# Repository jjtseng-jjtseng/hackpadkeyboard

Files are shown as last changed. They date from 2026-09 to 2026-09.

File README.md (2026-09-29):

# My HackPad Keyboard

A keyboard that can type an absurdly large amount of characters in a short space.
By combining the 16 keys with the knob, each turn of the knob makes each key type a different thing. This way, you can go from your normal A B C's to weird hieroglyphics.

# Features/Things used:

- 3d printed case (bottom section with a usb c hole wita top cover with a knob and key hole(s))
- 99.5 x99.5 mm pcb with a 4x4 matrix of buttons on it (+ knob)
- 16 LED's for each of buttons (cool lighting effects)

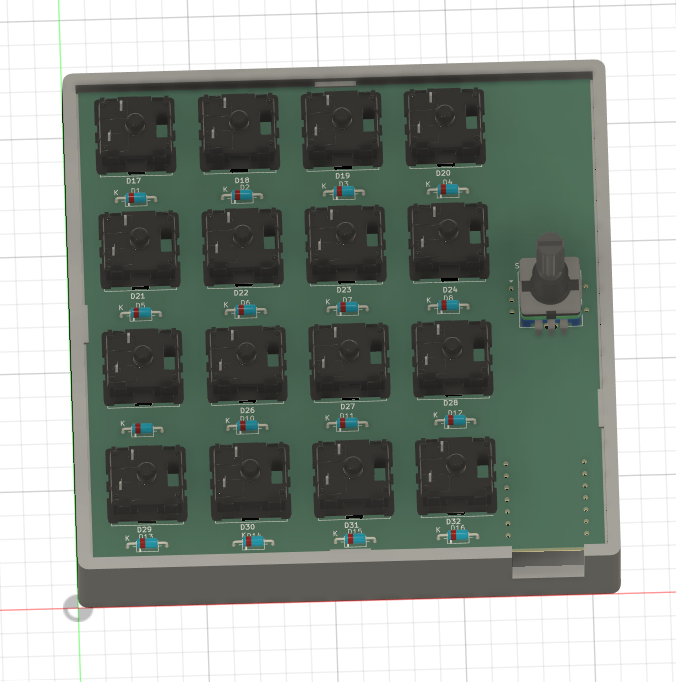
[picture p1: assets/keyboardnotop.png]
Top View

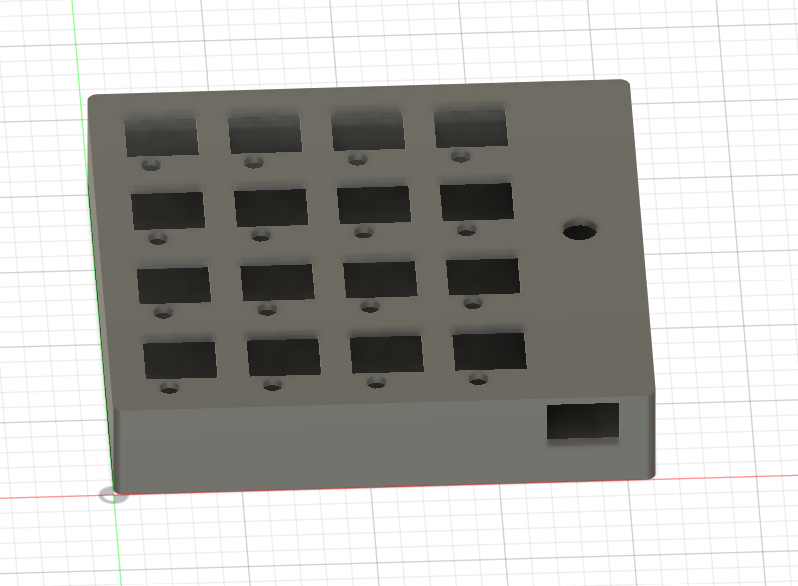
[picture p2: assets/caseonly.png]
Caseonly


# CAD
Used fusion 360
Pretty easy. Bottom case with usb c hole + top case with key, knob, and LED holes.

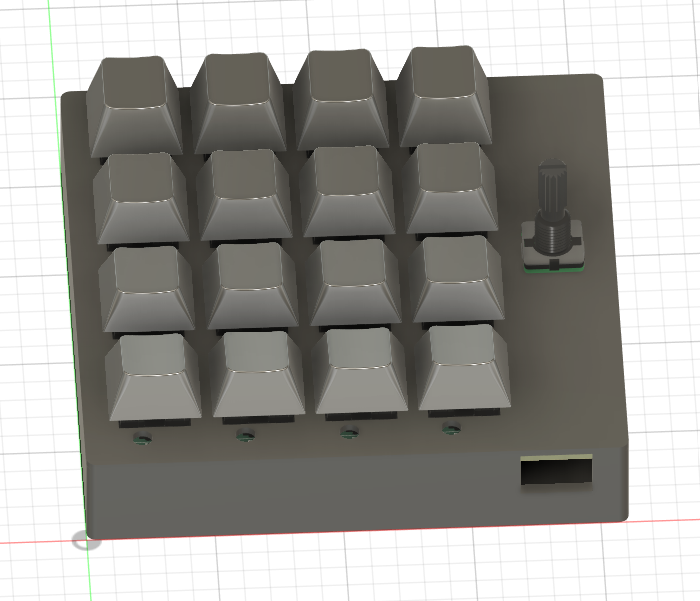
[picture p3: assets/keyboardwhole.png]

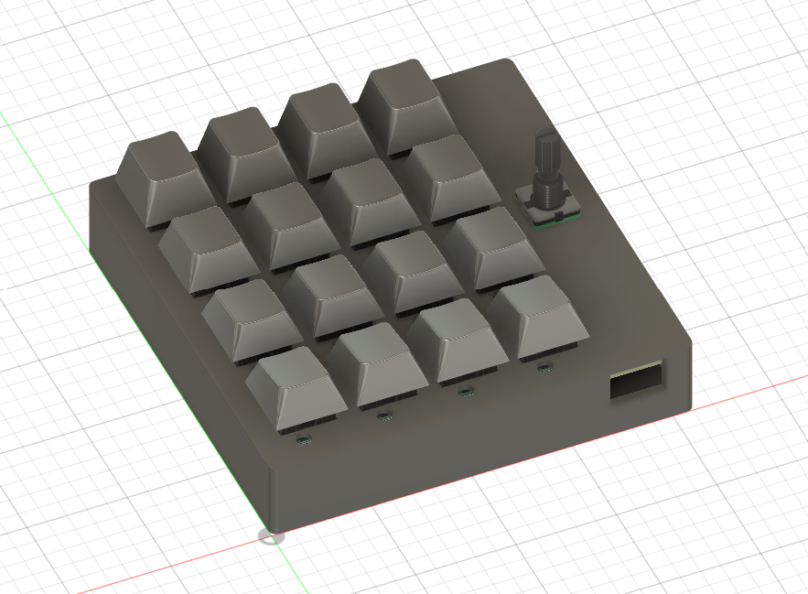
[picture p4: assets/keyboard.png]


# PCB

PCB pics attached below.
Kicad used

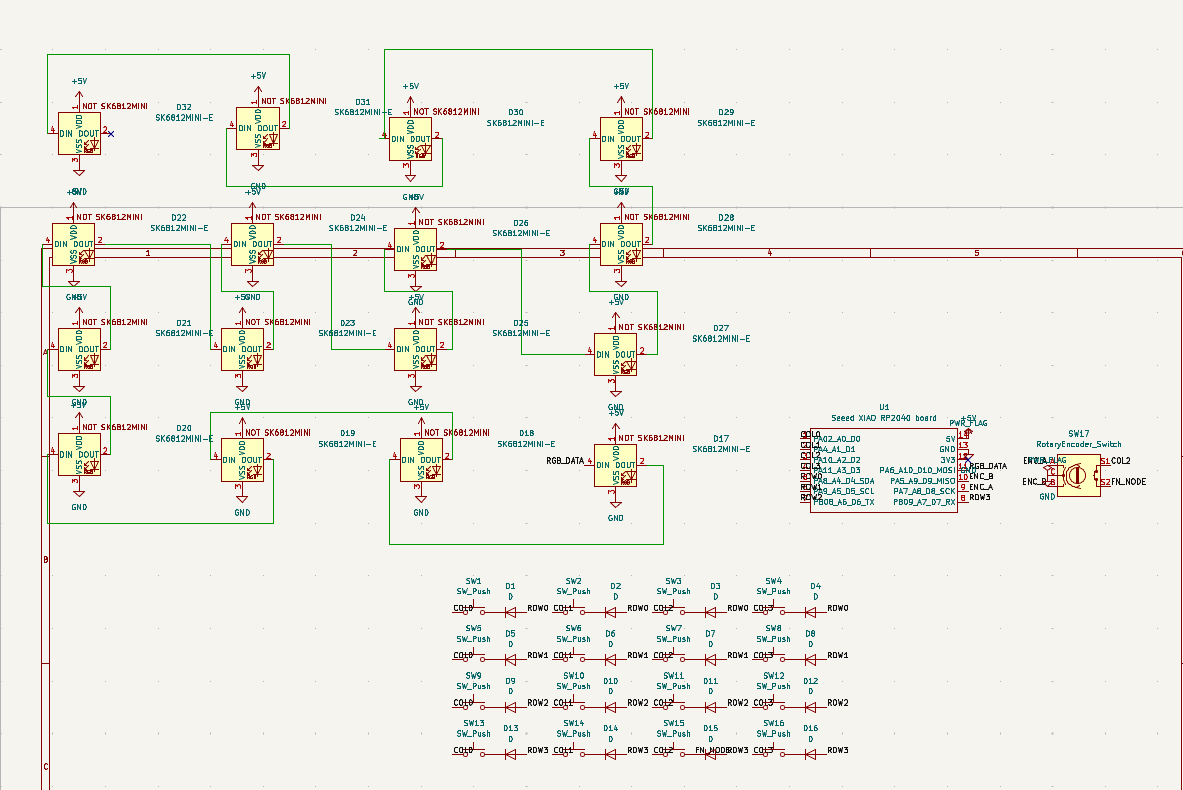
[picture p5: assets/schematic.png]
Schematic

Schematic
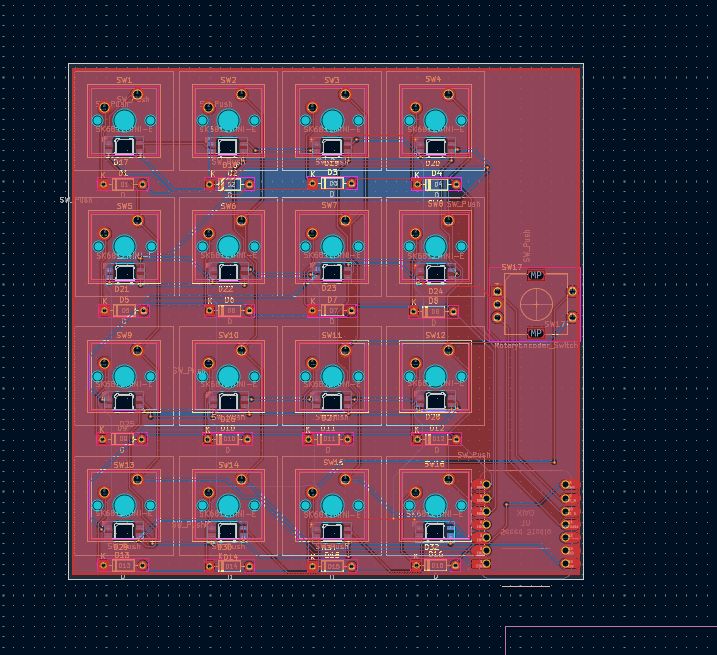
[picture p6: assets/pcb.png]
PCB

PCB
CAD render:
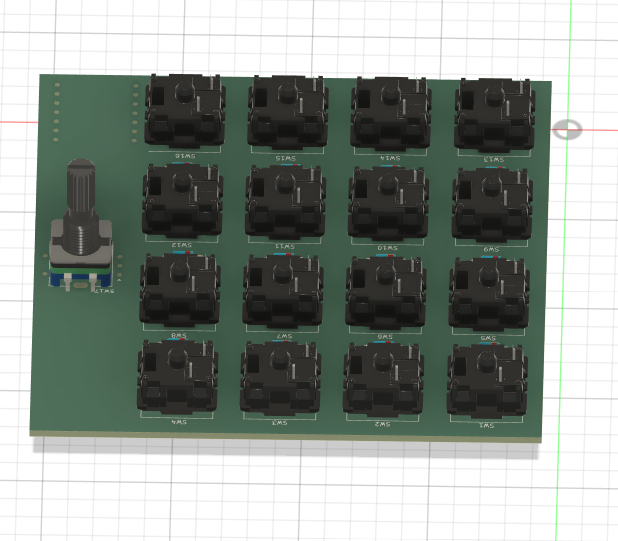
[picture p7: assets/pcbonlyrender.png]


# Firmware:
Python with a main.py used.

#How the final product should look:

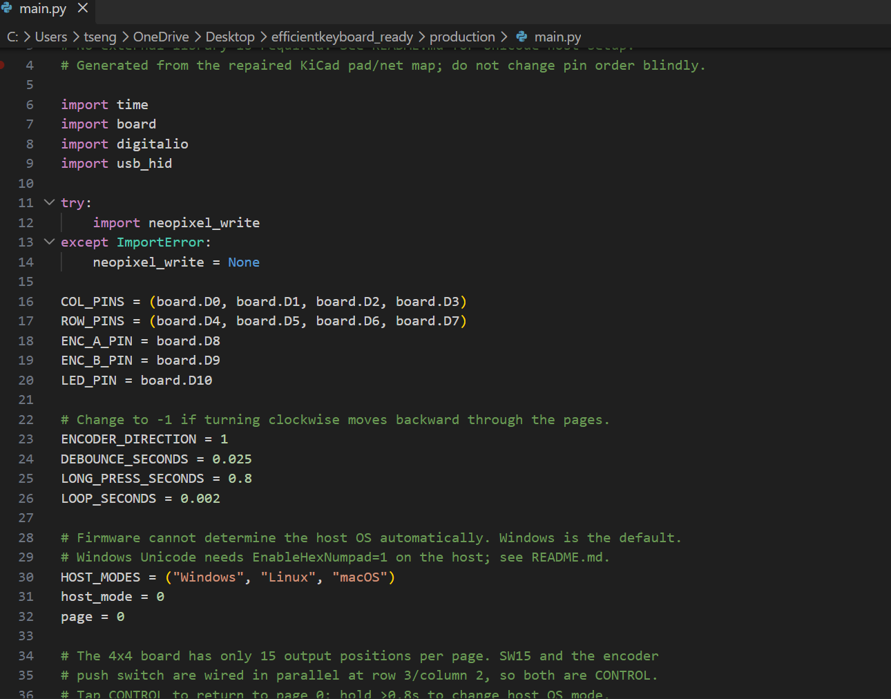
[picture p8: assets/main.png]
Code

Main.py

# BOM

Everything that is needed to make this:

- 1x custom pcb
- 1x Rotary encoder
- 1x Seeed XIAO RP2040
- 16x SK6812MINI-E RGB LEDs
- 16x DSA keycaps
- 16x 1N4148 Diodes
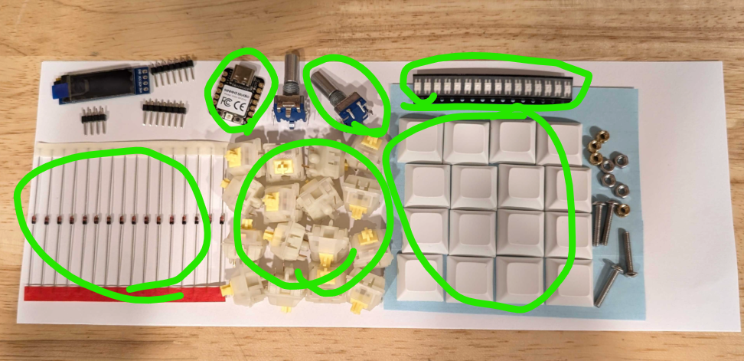
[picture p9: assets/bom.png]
stuffused


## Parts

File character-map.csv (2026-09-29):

Page | Name | SW1 | SW2 | SW3 | SW4 | SW5 | SW6 | SW7 | SW8 | SW9 | SW10 | SW11 | SW12 | SW13 | SW14 | SW15 | SW16
0 | QWERTY 1 | q | w | e | r | t | y | u | i | o | p | a | s | d | f | CONTROL | g
1 | QWERTY 2 | h | j | k | l | z | x | c | v | b | n | m | SPACE | BACKSPACE | ENTER | CONTROL | TAB
2 | Digits | 1 | 2 | 3 | 4 | 5 | 6 | 7 | 8 | 9 | 0 | - | = | , | . | CONTROL | /
3 | Common symbols | ! | @ | # | $ | % | ^ | & | * | ( | ) | _ | + | ? | : | CONTROL | ;
4 | More symbols | [ | ] | { | } | \ | | | ~ | < | > | " | ' | ` | A | ESCAPE | CONTROL | DELETE
5 | Latin 1 1 | ¡ U+00A1 | ¢ U+00A2 | £ U+00A3 | ¤ U+00A4 | ¥ U+00A5 | ¦ U+00A6 | § U+00A7 | ¨ U+00A8 | © U+00A9 | ª U+00AA | « U+00AB | ¬ U+00AC | ® U+00AE | ¯ U+00AF | CONTROL | ° U+00B0
6 | Latin 1 2 | ± U+00B1 | ² U+00B2 | ³ U+00B3 | ´ U+00B4 | µ U+00B5 | ¶ U+00B6 | · U+00B7 | ¸ U+00B8 | ¹ U+00B9 | º U+00BA | » U+00BB | ¼ U+00BC | ½ U+00BD | ¾ U+00BE | CONTROL | ¿ U+00BF
7 | Latin 1 3 | À U+00C0 | Á U+00C1 | Â U+00C2 | Ã U+00C3 | Ä U+00C4 | Å U+00C5 | Æ U+00C6 | Ç U+00C7 | È U+00C8 | É U+00C9 | Ê U+00CA | Ë U+00CB | Ì U+00CC | Í U+00CD | CONTROL | Î U+00CE
8 | Latin Extended A 1 | Ā U+0100 | ā U+0101 | Ă U+0102 | ă U+0103 | Ą U+0104 | ą U+0105 | Ć U+0106 | ć U+0107 | Ĉ U+0108 | ĉ U+0109 | Ċ U+010A | ċ U+010B | Č U+010C | č U+010D | CONTROL | Ď U+010E
9 | Latin Extended A 2 | ď U+010F | Đ U+0110 | đ U+0111 | Ē U+0112 | ē U+0113 | Ĕ U+0114 | ĕ U+0115 | Ė U+0116 | ė U+0117 | Ę U+0118 | ę U+0119 | Ě U+011A | ě U+011B | Ĝ U+011C | CONTROL | ĝ U+011D
10 | Latin Extended A 3 | Ğ U+011E | ğ U+011F | Ġ U+0120 | ġ U+0121 | Ģ U+0122 | ģ U+0123 | Ĥ U+0124 | ĥ U+0125 | Ħ U+0126 | ħ U+0127 | Ĩ U+0128 | ĩ U+0129 | Ī U+012A | ī U+012B | CONTROL | Ĭ U+012C
11 | Latin Extended A 4 | ĭ U+012D | Į U+012E | į U+012F | İ U+0130 | ı U+0131 | Ĳ U+0132 | ĳ U+0133 | Ĵ U+0134 | ĵ U+0135 | Ķ U+0136 | ķ U+0137 | ĸ U+0138 | Ĺ U+0139 | ĺ U+013A | CONTROL | Ļ U+013B
12 | Latin Extended A 5 | ļ U+013C | Ľ U+013D | ľ U+013E | Ŀ U+013F | ŀ U+0140 | Ł U+0141 | ł U+0142 | Ń U+0143 | ń U+0144 | Ņ U+0145 | ņ U+0146 | Ň U+0147 | ň U+0148 | ŉ U+0149 | CONTROL | Ŋ U+014A
13 | Latin Extended B 1 | ƀ U+0180 | Ɓ U+0181 | Ƃ U+0182 | ƃ U+0183 | Ƅ U+0184 | ƅ U+0185 | Ɔ U+0186 | Ƈ U+0187 | ƈ U+0188 | Ɖ U+0189 | Ɗ U+018A | Ƌ U+018B | ƌ U+018C | ƍ U+018D | CONTROL | Ǝ U+018E
14 | Latin Extended B 2 | Ə U+018F | Ɛ U+0190 | Ƒ U+0191 | ƒ U+0192 | Ɠ U+0193 | Ɣ U+0194 | ƕ U+0195 | Ɩ U+0196 | Ɨ U+0197 | Ƙ U+0198 | ƙ U+0199 | ƚ U+019A | ƛ U+019B | Ɯ U+019C | CONTROL | Ɲ U+019D
15 | Latin Extended B 3 | ƞ U+019E | Ɵ U+019F | Ơ U+01A0 | ơ U+01A1 | Ƣ U+01A2 | ƣ U+01A3 | Ƥ U+01A4 | ƥ U+01A5 | Ʀ U+01A6 | Ƨ U+01A7 | ƨ U+01A8 | Ʃ U+01A9 | ƪ U+01AA | ƫ U+01AB | CONTROL | Ƭ U+01AC
16 | Latin Extended B 4 | ƭ U+01AD | Ʈ U+01AE | Ư U+01AF | ư U+01B0 | Ʊ U+01B1 | Ʋ U+01B2 | Ƴ U+01B3 | ƴ U+01B4 | Ƶ U+01B5 | ƶ U+01B6 | Ʒ U+01B7 | Ƹ U+01B8 | ƹ U+01B9 | ƺ U+01BA | CONTROL | ƻ U+01BB
17 | IPA 1 | ɐ U+0250 | ɑ U+0251 | ɒ U+0252 | ɓ U+0253 | ɔ U+0254 | ɕ U+0255 | ɖ U+0256 | ɗ U+0257 | ɘ U+0258 | ə U+0259 | ɚ U+025A | ɛ U+025B | ɜ U+025C | ɝ U+025D | CONTROL | ɞ U+025E
18 | IPA 2 | ɟ U+025F | ɠ U+0260 | ɡ U+0261 | ɢ U+0262 | ɣ U+0263 | ɤ U+0264 | ɥ U+0265 | ɦ U+0266 | ɧ U+0267 | ɨ U+0268 | ɩ U+0269 | ɪ U+026A | ɫ U+026B | ɬ U+026C | CONTROL | ɭ U+026D
19 | Greek 1 | Ͱ U+0370 | ͱ U+0371 | Ͳ U+0372 | ͳ U+0373 | ʹ U+0374 | ͵ U+0375 | Ͷ U+0376 | ͷ U+0377 | ͺ U+037A | ͻ U+037B | ͼ U+037C | ͽ U+037D | ; U+037E | Ϳ U+037F | CONTROL | ΄ U+0384
20 | Greek 2 | ΅ U+0385 | Ά U+0386 | · U+0387 | Έ U+0388 | Ή U+0389 | Ί U+038A | Ό U+038C | Ύ U+038E | Ώ U+038F | ΐ U+0390 | Α U+0391 | Β U+0392 | Γ U+0393 | Δ U+0394 | CONTROL | Ε U+0395
21 | Greek 3 | Ζ U+0396 | Η U+0397 | Θ U+0398 | Ι U+0399 | Κ U+039A | Λ U+039B | Μ U+039C | Ν U+039D | Ξ U+039E | Ο U+039F | Π U+03A0 | Ρ U+03A1 | Σ U+03A3 | Τ U+03A4 | CONTROL | Υ U+03A5
22 | Greek 4 | Φ U+03A6 | Χ U+03A7 | Ψ U+03A8 | Ω U+03A9 | Ϊ U+03AA | Ϋ U+03AB | ά U+03AC | έ U+03AD | ή U+03AE | ί U+03AF | ΰ U+03B0 | α U+03B1 | β U+03B2 | γ U+03B3 | CONTROL | δ U+03B4
23 | Cyrillic 1 | Ѐ U+0400 | Ё U+0401 | Ђ U+0402 | Ѓ U+0403 | Є U+0404 | Ѕ U+0405 | І U+0406 | Ї U+0407 | Ј U+0408 | Љ U+0409 | Њ U+040A | Ћ U+040B | Ќ U+040C | Ѝ U+040D | CONTROL | Ў U+040E
24 | Cyrillic 2 | Џ U+040F | А U+0410 | Б U+0411 | В U+0412 | Г U+0413 | Д U+0414 | Е U+0415 | Ж U+0416 | З U+0417 | И U+0418 | Й U+0419 | К U+041A | Л U+041B | М U+041C | CONTROL | Н U+041D
25 | Cyrillic 3 | О U+041E | П U+041F | Р U+0420 | С U+0421 | Т U+0422 | У U+0423 | Ф U+0424 | Х U+0425 | Ц U+0426 | Ч U+0427 | Ш U+0428 | Щ U+0429 | Ъ U+042A | Ы U+042B | CONTROL | Ь U+042C
26 | Cyrillic 4 | Э U+042D | Ю U+042E | Я U+042F | а U+0430 | б U+0431 | в U+0432 | г U+0433 | д U+0434 | е U+0435 | ж U+0436 | з U+0437 | и U+0438 | й U+0439 | к U+043A | CONTROL | л U+043B
27 | Cyrillic 5 | м U+043C | н U+043D | о U+043E | п U+043F | р U+0440 | с U+0441 | т U+0442 | у U+0443 | ф U+0444 | х U+0445 | ц U+0446 | ч U+0447 | ш U+0448 | щ U+0449 | CONTROL | ъ U+044A
28 | Armenian 1 | Ա U+0531 | Բ U+0532 | Գ U+0533 | Դ U+0534 | Ե U+0535 | Զ U+0536 | Է U+0537 | Ը U+0538 | Թ U+0539 | Ժ U+053A | Ի U+053B | Լ U+053C | Խ U+053D | Ծ U+053E | CONTROL | Կ U+053F
29 | Armenian 2 | Հ U+0540 | Ձ U+0541 | Ղ U+0542 | Ճ U+0543 | Մ U+0544 | Յ U+0545 | Ն U+0546 | Շ U+0547 | Ո U+0548 | Չ U+0549 | Պ U+054A | Ջ U+054B | Ռ U+054C | Ս U+054D | CONTROL | Վ U+054E
30 | Hebrew 1 | ־ U+05BE | ׀ U+05C0 | ׃ U+05C3 | ׆ U+05C6 | א U+05D0 | ב U+05D1 | ג U+05D2 | ד U+05D3 | ה U+05D4 | ו U+05D5 | ז U+05D6 | ח U+05D7 | ט U+05D8 | י U+05D9 | CONTROL | ך U+05DA
31 | Hebrew 2 | כ U+05DB | ל U+05DC | ם U+05DD | מ U+05DE | ן U+05DF | נ U+05E0 | ס U+05E1 | ע U+05E2 | ף U+05E3 | פ U+05E4 | ץ U+05E5 | צ U+05E6 | ק U+05E7 | ר U+05E8 | CONTROL | ש U+05E9
32 | Arabic 1 | ؆ U+0606 | ؇ U+0607 | ؈ U+0608 | ؉ U+0609 | ؊ U+060A | ؋ U+060B | ، U+060C | ؍ U+060D | ؎ U+060E | ؏ U+060F | ؛ U+061B | ؝ U+061D | ؞ U+061E | ؟ U+061F | CONTROL | ؠ U+0620
33 | Arabic 2 | ء U+0621 | آ U+0622 | أ U+0623 | ؤ U+0624 | إ U+0625 | ئ U+0626 | ا U+0627 | ب U+0628 | ة U+0629 | ت U+062A | ث U+062B | ج U+062C | ح U+062D | خ U+062E | CONTROL | د U+062F
34 | Arabic 3 | ذ U+0630 | ر U+0631 | ز U+0632 | س U+0633 | ش U+0634 | ص U+0635 | ض U+0636 | ط U+0637 | ظ U+0638 | ع U+0639 | غ U+063A | ػ U+063B | ؼ U+063C | ؽ U+063D | CONTROL | ؾ U+063E
35 | Devanagari 1 | ऄ U+0904 | अ U+0905 | आ U+0906 | इ U+0907 | ई U+0908 | उ U+0909 | ऊ U+090A | ऋ U+090B | ऌ U+090C | ऍ U+090D | ऎ U+090E | ए U+090F | ऐ U+0910 | ऑ U+0911 | CONTROL | ऒ U+0912
36 | Devanagari 2 | ओ U+0913 | औ U+0914 | क U+0915 | ख U+0916 | ग U+0917 | घ U+0918 | ङ U+0919 | च U+091A | छ U+091B | ज U+091C | झ U+091D | ञ U+091E | ट U+091F | ठ U+0920 | CONTROL | ड U+0921
37 | Bengali 1 | ঀ U+0980 | অ U+0985 | আ U+0986 | ই U+0987 | ঈ U+0988 | উ U+0989 | ঊ U+098A | ঋ U+098B | ঌ U+098C | এ U+098F | ঐ U+0990 | ও U+0993 | ঔ U+0994 | ক U+0995 | CONTROL | খ U+0996
38 | Tamil 1 | ஃ U+0B83 | அ U+0B85 | ஆ U+0B86 | இ U+0B87 | ஈ U+0B88 | உ U+0B89 | ஊ U+0B8A | எ U+0B8E | ஏ U+0B8F | ஐ U+0B90 | ஒ U+0B92 | ஓ U+0B93 | ஔ U+0B94 | க U+0B95 | CONTROL | ங U+0B99
39 | Thai 1 | ก U+0E01 | ข U+0E02 | ฃ U+0E03 | ค U+0E04 | ฅ U+0E05 | ฆ U+0E06 | ง U+0E07 | จ U+0E08 | ฉ U+0E09 | ช U+0E0A | ซ U+0E0B | ฌ U+0E0C | ญ U+0E0D | ฎ U+0E0E | CONTROL | ฏ U+0E0F
40 | Thai 2 | ฐ U+0E10 | ฑ U+0E11 | ฒ U+0E12 | ณ U+0E13 | ด U+0E14 | ต U+0E15 | ถ U+0E16 | ท U+0E17 | ธ U+0E18 | น U+0E19 | บ U+0E1A | ป U+0E1B | ผ U+0E1C | ฝ U+0E1D | CONTROL | พ U+0E1E
41 | Georgian 1 | Ⴀ U+10A0 | Ⴁ U+10A1 | Ⴂ U+10A2 | Ⴃ U+10A3 | Ⴄ U+10A4 | Ⴅ U+10A5 | Ⴆ U+10A6 | Ⴇ U+10A7 | Ⴈ U+10A8 | Ⴉ U+10A9 | Ⴊ U+10AA | Ⴋ U+10AB | Ⴌ U+10AC | Ⴍ U+10AD | CONTROL | Ⴎ U+10AE
42 | Georgian 2 | Ⴏ U+10AF | Ⴐ U+10B0 | Ⴑ U+10B1 | Ⴒ U+10B2 | Ⴓ U+10B3 | Ⴔ U+10B4 | Ⴕ U+10B5 | Ⴖ U+10B6 | Ⴗ U+10B7 | Ⴘ U+10B8 | Ⴙ U+10B9 | Ⴚ U+10BA | Ⴛ U+10BB | Ⴜ U+10BC | CONTROL | Ⴝ U+10BD
43 | Ethiopic 1 | ሀ U+1200 | ሁ U+1201 | ሂ U+1202 | ሃ U+1203 | ሄ U+1204 | ህ U+1205 | ሆ U+1206 | ሇ U+1207 | ለ U+1208 | ሉ U+1209 | ሊ U+120A | ላ U+120B | ሌ U+120C | ል U+120D | CONTROL | ሎ U+120E
44 | Ethiopic 2 | ሏ U+120F | ሐ U+1210 | ሑ U+1211 | ሒ U+1212 | ሓ U+1213 | ሔ U+1214 | ሕ U+1215 | ሖ U+1216 | ሗ U+1217 | መ U+1218 | ሙ U+1219 | ሚ U+121A | ማ U+121B | ሜ U+121C | CONTROL | ም U+121D
45 | Ethiopic 3 | ሞ U+121E | ሟ U+121F | ሠ U+1220 | ሡ U+1221 | ሢ U+1222 | ሣ U+1223 | ሤ U+1224 | ሥ U+1225 | ሦ U+1226 | ሧ U+1227 | ረ U+1228 | ሩ U+1229 | ሪ U+122A | ራ U+122B | CONTROL | ሬ U+122C
46 | Ethiopic 4 | ር U+122D | ሮ U+122E | ሯ U+122F | ሰ U+1230 | ሱ U+1231 | ሲ U+1232 | ሳ U+1233 | ሴ U+1234 | ስ U+1235 | ሶ U+1236 | ሷ U+1237 | ሸ U+1238 | ሹ U+1239 | ሺ U+123A | CONTROL | ሻ U+123B
47 | Cherokee 1 | Ꭰ U+13A0 | Ꭱ U+13A1 | Ꭲ U+13A2 | Ꭳ U+13A3 | Ꭴ U+13A4 | Ꭵ U+13A5 | Ꭶ U+13A6 | Ꭷ U+13A7 | Ꭸ U+13A8 | Ꭹ U+13A9 | Ꭺ U+13AA | Ꭻ U+13AB | Ꭼ U+13AC | Ꭽ U+13AD | CONTROL | Ꭾ U+13AE
48 | Cherokee 2 | Ꭿ U+13AF | Ꮀ U+13B0 | Ꮁ U+13B1 | Ꮂ U+13B2 | Ꮃ U+13B3 | Ꮄ U+13B4 | Ꮅ U+13B5 | Ꮆ U+13B6 | Ꮇ U+13B7 | Ꮈ U+13B8 | Ꮉ U+13B9 | Ꮊ U+13BA | Ꮋ U+13BB | Ꮌ U+13BC | CONTROL | Ꮍ U+13BD
49 | Canadian syllabics 1 | ᐀ U+1400 | ᐁ U+1401 | ᐂ U+1402 | ᐃ U+1403 | ᐄ U+1404 | ᐅ U+1405 | ᐆ U+1406 | ᐇ U+1407 | ᐈ U+1408 | ᐉ U+1409 | ᐊ U+140A | ᐋ U+140B | ᐌ U+140C | ᐍ U+140D | CONTROL | ᐎ U+140E
50 | Canadian syllabics 2 | ᐏ U+140F | ᐐ U+1410 | ᐑ U+1411 | ᐒ U+1412 | ᐓ U+1413 | ᐔ U+1414 | ᐕ U+1415 | ᐖ U+1416 | ᐗ U+1417 | ᐘ U+1418 | ᐙ U+1419 | ᐚ U+141A | ᐛ U+141B | ᐜ U+141C | CONTROL | ᐝ U+141D
51 | Canadian syllabics 3 | ᐞ U+141E | ᐟ U+141F | ᐠ U+1420 | ᐡ U+1421 | ᐢ U+1422 | ᐣ U+1423 | ᐤ U+1424 | ᐥ U+1425 | ᐦ U+1426 | ᐧ U+1427 | ᐨ U+1428 | ᐩ U+1429 | ᐪ U+142A | ᐫ U+142B | CONTROL | ᐬ U+142C
52 | Runic 1 | ᚠ U+16A0 | ᚡ U+16A1 | ᚢ U+16A2 | ᚣ U+16A3 | ᚤ U+16A4 | ᚥ U+16A5 | ᚦ U+16A6 | ᚧ U+16A7 | ᚨ U+16A8 | ᚩ U+16A9 | ᚪ U+16AA | ᚫ U+16AB | ᚬ U+16AC | ᚭ U+16AD | CONTROL | ᚮ U+16AE
53 | Runic 2 | ᚯ U+16AF | ᚰ U+16B0 | ᚱ U+16B1 | ᚲ U+16B2 | ᚳ U+16B3 | ᚴ U+16B4 | ᚵ U+16B5 | ᚶ U+16B6 | ᚷ U+16B7 | ᚸ U+16B8 | ᚹ U+16B9 | ᚺ U+16BA | ᚻ U+16BB | ᚼ U+16BC | CONTROL | ᚽ U+16BD
54 | Hiragana 1 | ぁ U+3041 | あ U+3042 | ぃ U+3043 | い U+3044 | ぅ U+3045 | う U+3046 | ぇ U+3047 | え U+3048 | ぉ U+3049 | お U+304A | か U+304B | が U+304C | き U+304D | ぎ U+304E | CONTROL | く U+304F
55 | Hiragana 2 | ぐ U+3050 | け U+3051 | げ U+3052 | こ U+3053 | ご U+3054 | さ U+3055 | ざ U+3056 | し U+3057 | じ U+3058 | す U+3059 | ず U+305A | せ U+305B | ぜ U+305C | そ U+305D | CONTROL | ぞ U+305E
56 | Katakana 1 | ゠ U+30A0 | ァ U+30A1 | ア U+30A2 | ィ U+30A3 | イ U+30A4 | ゥ U+30A5 | ウ U+30A6 | ェ U+30A7 | エ U+30A8 | ォ U+30A9 | オ U+30AA | カ U+30AB | ガ U+30AC | キ U+30AD | CONTROL | ギ U+30AE
57 | Katakana 2 | ク U+30AF | グ U+30B0 | ケ U+30B1 | ゲ U+30B2 | コ U+30B3 | ゴ U+30B4 | サ U+30B5 | ザ U+30B6 | シ U+30B7 | ジ U+30B8 | ス U+30B9 | ズ U+30BA | セ U+30BB | ゼ U+30BC | CONTROL | ソ U+30BD
58 | CJK 1 | 一 U+4E00 | 丁 U+4E01 | 丂 U+4E02 | 七 U+4E03 | 丄 U+4E04 | 丅 U+4E05 | 丆 U+4E06 | 万 U+4E07 | 丈 U+4E08 | 三 U+4E09 | 上 U+4E0A | 下 U+4E0B | 丌 U+4E0C | 不 U+4E0D | CONTROL | 与 U+4E0E
59 | CJK 2 | 丏 U+4E0F | 丐 U+4E10 | 丑 U+4E11 | 丒 U+4E12 | 专 U+4E13 | 且 U+4E14 | 丕 U+4E15 | 世 U+4E16 | 丗 U+4E17 | 丘 U+4E18 | 丙 U+4E19 | 业 U+4E1A | 丛 U+4E1B | 东 U+4E1C | CONTROL | 丝 U+4E1D
60 | CJK 3 | 丞 U+4E1E | 丟 U+4E1F | 丠 U+4E20 | 両 U+4E21 | 丢 U+4E22 | 丣 U+4E23 | 两 U+4E24 | 严 U+4E25 | 並 U+4E26 | 丧 U+4E27 | 丨 U+4E28 | 丩 U+4E29 | 个 U+4E2A | 丫 U+4E2B | CONTROL | 丬 U+4E2C
61 | Arrows 1 | ← U+2190 | ↑ U+2191 | → U+2192 | ↓ U+2193 | ↔ U+2194 | ↕ U+2195 | ↖ U+2196 | ↗ U+2197 | ↘ U+2198 | ↙ U+2199 | ↚ U+219A | ↛ U+219B | ↜ U+219C | ↝ U+219D | CONTROL | ↞ U+219E
62 | Arrows 2 | ↟ U+219F | ↠ U+21A0 | ↡ U+21A1 | ↢ U+21A2 | ↣ U+21A3 | ↤ U+21A4 | ↥ U+21A5 | ↦ U+21A6 | ↧ U+21A7 | ↨ U+21A8 | ↩ U+21A9 | ↪ U+21AA | ↫ U+21AB | ↬ U+21AC | CONTROL | ↭ U+21AD
63 | Math 1 | ∀ U+2200 | ∁ U+2201 | ∂ U+2202 | ∃ U+2203 | ∄ U+2204 | ∅ U+2205 | ∆ U+2206 | ∇ U+2207 | ∈ U+2208 | ∉ U+2209 | ∊ U+220A | ∋ U+220B | ∌ U+220C | ∍ U+220D | CONTROL | ∎ U+220E
64 | Math 2 | ∏ U+220F | ∐ U+2210 | ∑ U+2211 | − U+2212 | ∓ U+2213 | ∔ U+2214 | ∕ U+2215 | ∖ U+2216 | ∗ U+2217 | ∘ U+2218 | ∙ U+2219 | √ U+221A | ∛ U+221B | ∜ U+221C | CONTROL | ∝ U+221D
65 | Math 3 | ∞ U+221E | ∟ U+221F | ∠ U+2220 | ∡ U+2221 | ∢ U+2222 | ∣ U+2223 | ∤ U+2224 | ∥ U+2225 | ∦ U+2226 | ∧ U+2227 | ∨ U+2228 | ∩ U+2229 | ∪ U+222A | ∫ U+222B | CONTROL | ∬ U+222C
66 | Technical 1 | ⌀ U+2300 | ⌁ U+2301 | ⌂ U+2302 | ⌃ U+2303 | ⌄ U+2304 | ⌅ U+2305 | ⌆ U+2306 | ⌇ U+2307 | ⌈ U+2308 | ⌉ U+2309 | ⌊ U+230A | ⌋ U+230B | ⌌ U+230C | ⌍ U+230D | CONTROL | ⌎ U+230E
67 | Technical 2 | ⌏ U+230F | ⌐ U+2310 | ⌑ U+2311 | ⌒ U+2312 | ⌓ U+2313 | ⌔ U+2314 | ⌕ U+2315 | ⌖ U+2316 | ⌗ U+2317 | ⌘ U+2318 | ⌙ U+2319 | ⌚ U+231A | ⌛ U+231B | ⌜ U+231C | CONTROL | ⌝ U+231D
68 | Box drawing 1 | ─ U+2500 | ━ U+2501 | │ U+2502 | ┃ U+2503 | ┄ U+2504 | ┅ U+2505 | ┆ U+2506 | ┇ U+2507 | ┈ U+2508 | ┉ U+2509 | ┊ U+250A | ┋ U+250B | ┌ U+250C | ┍ U+250D | CONTROL | ┎ U+250E
69 | Box drawing 2 | ┏ U+250F | ┐ U+2510 | ┑ U+2511 | ┒ U+2512 | ┓ U+2513 | └ U+2514 | ┕ U+2515 | ┖ U+2516 | ┗ U+2517 | ┘ U+2518 | ┙ U+2519 | ┚ U+251A | ┛ U+251B | ├ U+251C | CONTROL | ┝ U+251D
70 | Geometric 1 | ■ U+25A0 | □ U+25A1 | ▢ U+25A2 | ▣ U+25A3 | ▤ U+25A4 | ▥ U+25A5 | ▦ U+25A6 | ▧ U+25A7 | ▨ U+25A8 | ▩ U+25A9 | ▪ U+25AA | ▫ U+25AB | ▬ U+25AC | ▭ U+25AD | CONTROL | ▮ U+25AE
71 | Geometric 2 | ▯ U+25AF | ▰ U+25B0 | ▱ U+25B1 | ▲ U+25B2 | △ U+25B3 | ▴ U+25B4 | ▵ U+25B5 | ▶ U+25B6 | ▷ U+25B7 | ▸ U+25B8 | ▹ U+25B9 | ► U+25BA | ▻ U+25BB | ▼ U+25BC | CONTROL | ▽ U+25BD
72 | Misc signs 1 | ☀ U+2600 | ☁ U+2601 | ☂ U+2602 | ☃ U+2603 | ☄ U+2604 | ★ U+2605 | ☆ U+2606 | ☇ U+2607 | ☈ U+2608 | ☉ U+2609 | ☊ U+260A | ☋ U+260B | ☌ U+260C | ☍ U+260D | CONTROL | ☎ U+260E
73 | Misc signs 2 | ☏ U+260F | ☐ U+2610 | ☑ U+2611 | ☒ U+2612 | ☓ U+2613 | ☔ U+2614 | ☕ U+2615 | ☖ U+2616 | ☗ U+2617 | ☘ U+2618 | ☙ U+2619 | ☚ U+261A | ☛ U+261B | ☜ U+261C | CONTROL | ☝ U+261D
74 | Misc signs 3 | ☞ U+261E | ☟ U+261F | ☠ U+2620 | ☡ U+2621 | ☢ U+2622 | ☣ U+2623 | ☤ U+2624 | ☥ U+2625 | ☦ U+2626 | ☧ U+2627 | ☨ U+2628 | ☩ U+2629 | ☪ U+262A | ☫ U+262B | CONTROL | ☬ U+262C
75 | Dingbats 1 | ✀ U+2700 | ✁ U+2701 | ✂ U+2702 | ✃ U+2703 | ✄ U+2704 | ✅ U+2705 | ✆ U+2706 | ✇ U+2707 | ✈ U+2708 | ✉ U+2709 | ✊ U+270A | ✋ U+270B | ✌ U+270C | ✍ U+270D | CONTROL | ✎ U+270E
76 | Dingbats 2 | ✏ U+270F | ✐ U+2710 | ✑ U+2711 | ✒ U+2712 | ✓ U+2713 | ✔ U+2714 | ✕ U+2715 | ✖ U+2716 | ✗ U+2717 | ✘ U+2718 | ✙ U+2719 | ✚ U+271A | ✛ U+271B | ✜ U+271C | CONTROL | ✝ U+271D
77 | Braille 1 | ⠀ U+2800 | ⠁ U+2801 | ⠂ U+2802 | ⠃ U+2803 | ⠄ U+2804 | ⠅ U+2805 | ⠆ U+2806 | ⠇ U+2807 | ⠈ U+2808 | ⠉ U+2809 | ⠊ U+280A | ⠋ U+280B | ⠌ U+280C | ⠍ U+280D | CONTROL | ⠎ U+280E
78 | Braille 2 | ⠏ U+280F | ⠐ U+2810 | ⠑ U+2811 | ⠒ U+2812 | ⠓ U+2813 | ⠔ U+2814 | ⠕ U+2815 | ⠖ U+2816 | ⠗ U+2817 | ⠘ U+2818 | ⠙ U+2819 | ⠚ U+281A | ⠛ U+281B | ⠜ U+281C | CONTROL | ⠝ U+281D
79 | Braille 3 | ⠞ U+281E | ⠟ U+281F | ⠠ U+2820 | ⠡ U+2821 | ⠢ U+2822 | ⠣ U+2823 | ⠤ U+2824 | ⠥ U+2825 | ⠦ U+2826 | ⠧ U+2827 | ⠨ U+2828 | ⠩ U+2829 | ⠪ U+282A | ⠫ U+282B | CONTROL | ⠬ U+282C

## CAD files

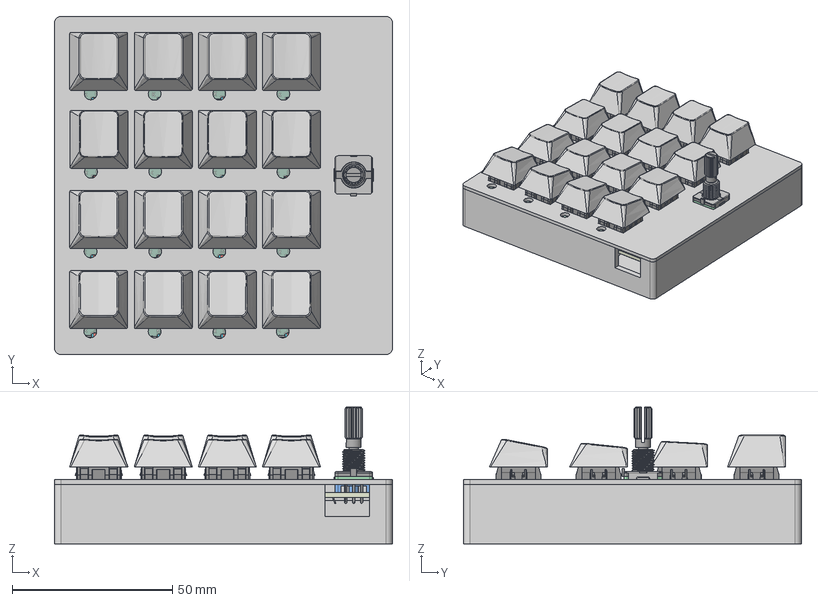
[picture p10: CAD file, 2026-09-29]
refrence/Keyboardcase-full-assembly.step
105.5 x 105.5 x 42.8 mm
D_DO-35_SOD27_P7.62mm_Horizontal_1 x 16
efficientkeyboard_silkscreen
efficientkeyboard_silkscreen_1
efficientkeyboard_soldermask
efficientkeyboard_soldermask_1
efficientkeyboard_PCB
r1_100 x 4
r2_100 x 4
r3_100 x 4
r4_100 x 4
MX_DOWN x 16
MX_UP x 16
UP_MX x 16
MX_PIN x 16
MX_SPRING x 16
MX_CLICK x 16
EC11_Rotary_Encoder_Switched

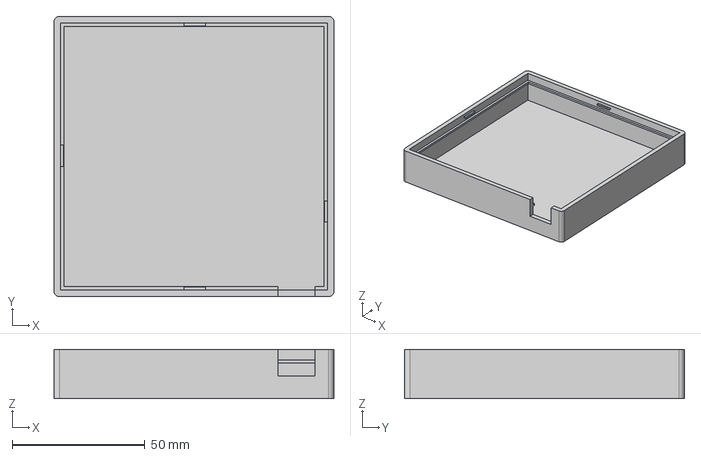
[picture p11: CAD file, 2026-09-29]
production/Bottom.step
105.5 x 105.5 x 18.6 mm

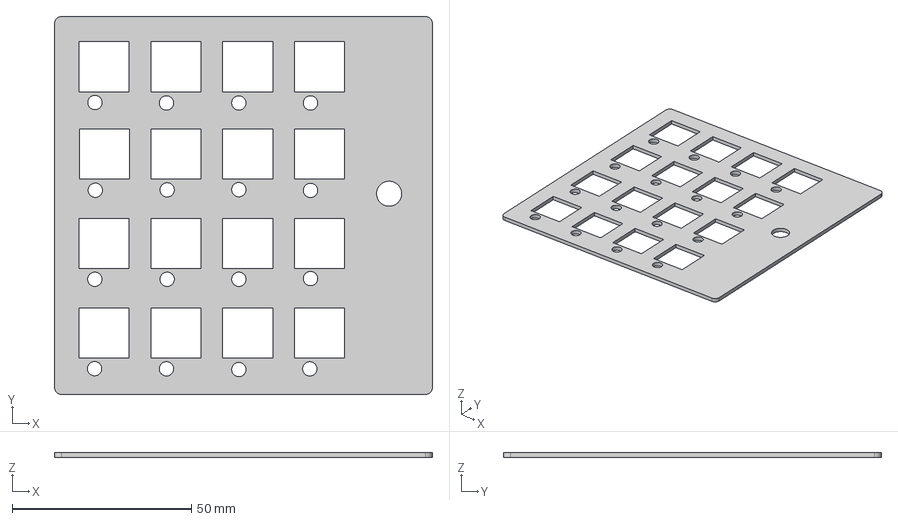
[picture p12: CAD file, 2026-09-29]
production/Top.step
105.5 x 105.5 x 1.50 mm

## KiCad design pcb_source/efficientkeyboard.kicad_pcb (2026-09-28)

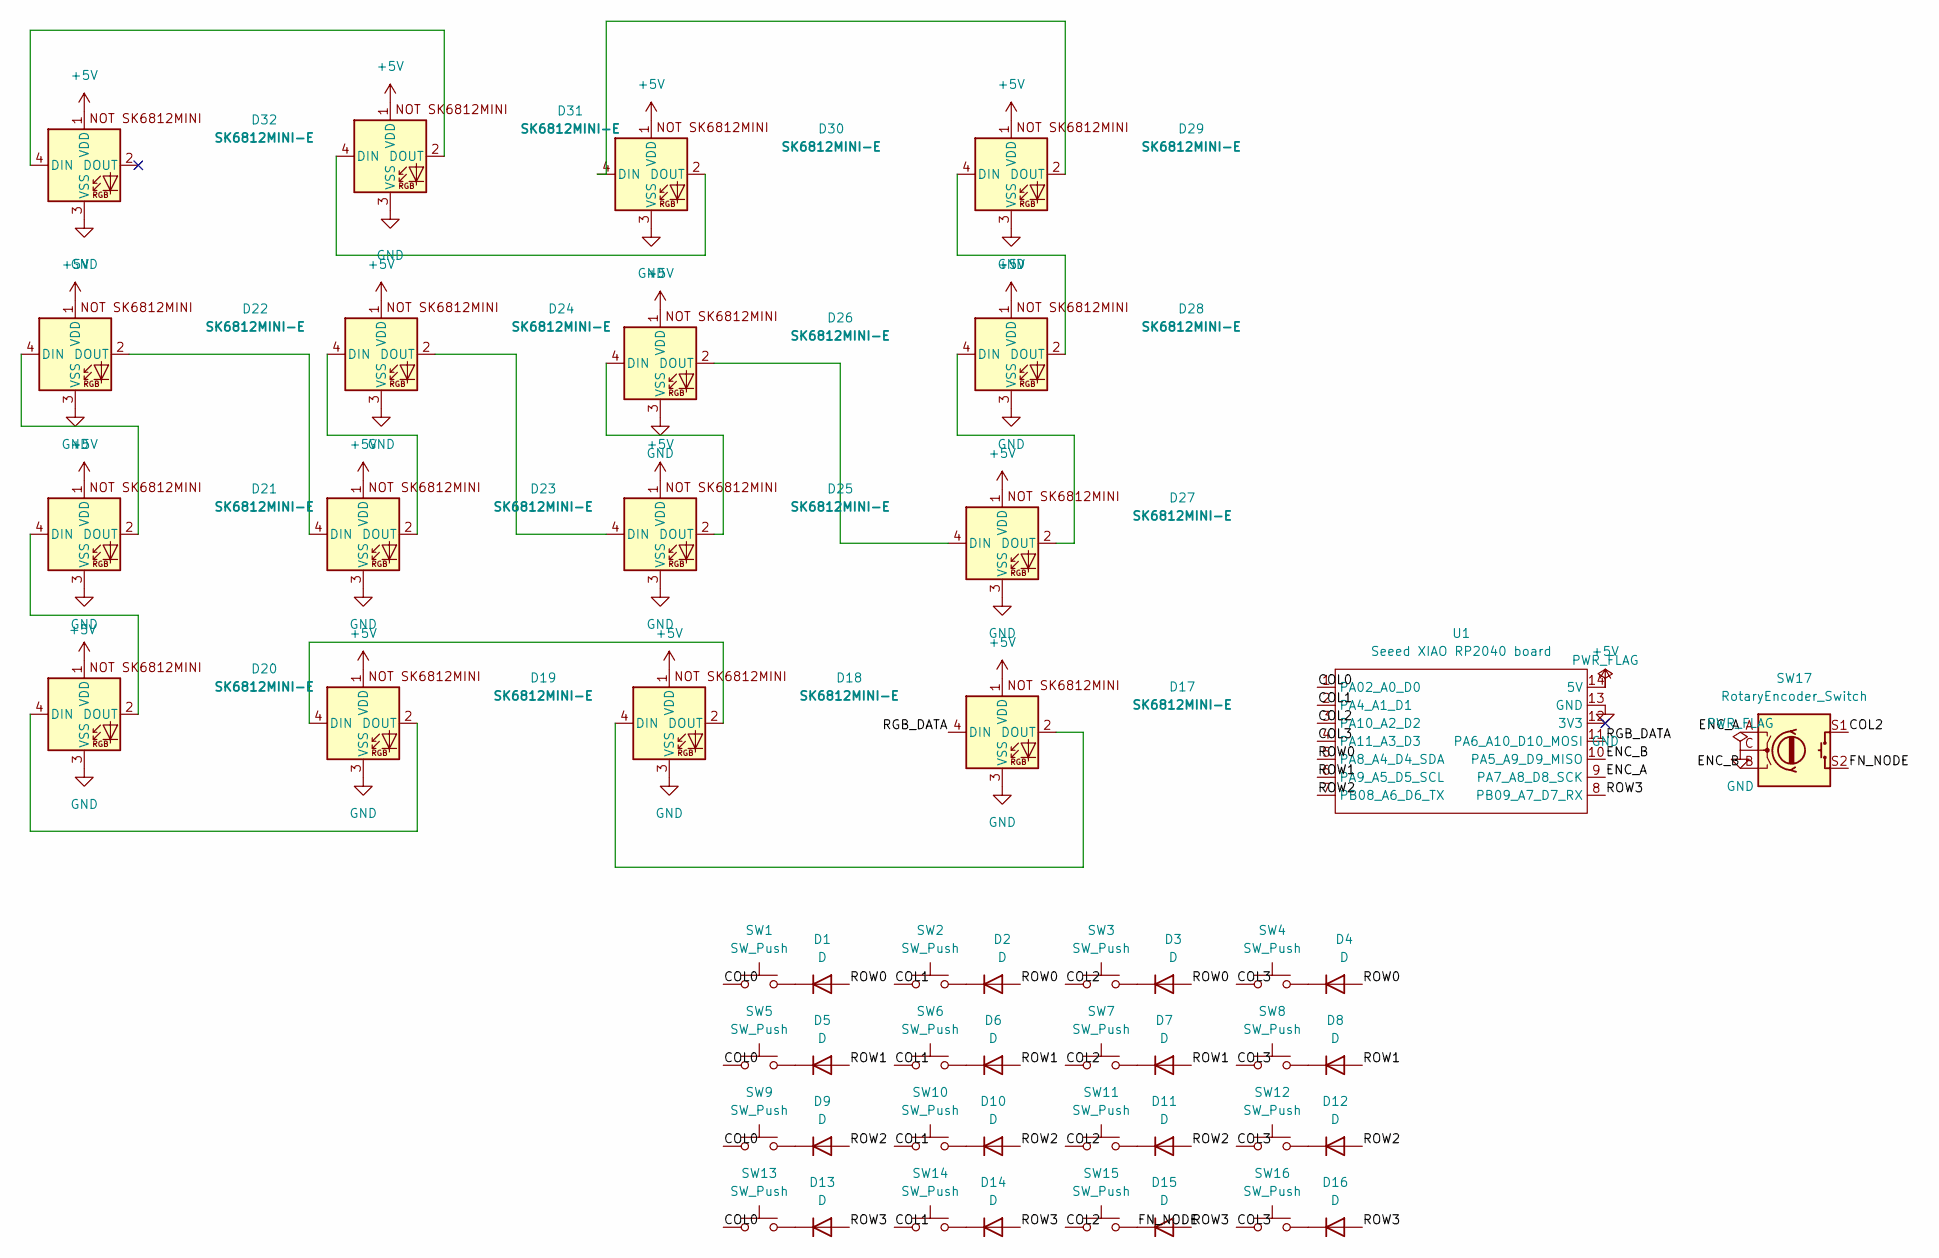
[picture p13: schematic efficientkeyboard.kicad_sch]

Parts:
D1, D2, D3, D4, D5, D6, D7, D8, D9, D10, D11, D12, D13, D14, D15, D16: D; D_DO-35_SOD27_P7.62mm_Horizontal
D17, D18, D19, D20, D21, D22, D23, D24, D25, D26, D27, D28, D29, D30, D31, D32: SK6812MINI-E; SK6812MINI-E_keyboard
SW1, SW2, SW3, SW4, SW5, SW6, SW7, SW8, SW9, SW10, SW11, SW12, SW13, SW14, SW15: SW_Push; SW_Cherry_MX_1.00u_PCB
SW16: SW_Push; SW_Cherry_MX_keyboard
SW17: RotaryEncoder_Switch; RotaryEncoder_Alps_EC11E-Switch_Vertical_H20mm
U1: Seeed XIAO RP2040 board; XIAO-Generic-Hybrid-keyboard

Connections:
+5V: D17.1 (VDD), D18.1 (VDD), D19.1 (VDD), D20.1 (VDD), D21.1 (VDD), D22.1 (VDD), D23.1 (VDD), D24.1 (VDD), D25.1 (VDD), D26.1 (VDD), D27.1 (VDD), D28.1 (VDD), D29.1 (VDD), D30.1 (VDD), D31.1 (VDD), D32.1 (VDD), U1.14 (5V)
/COL0: SW1.1, SW5.1, SW9.1, SW13.1, U1.1 (PA02_A0_D0)
/COL1: SW2.1, SW6.1, SW10.1, SW14.1, U1.2 (PA4_A1_D1)
/COL2: SW3.1, SW7.1, SW11.1, SW15.1, SW17.S1, U1.3 (PA10_A2_D2)
/COL3: SW4.1, SW8.1, SW12.1, SW16.1, U1.4 (PA11_A3_D3)
/ENC_A: SW17.A, U1.9 (PA7_A8_D8_SCK)
/ENC_B: SW17.B, U1.10 (PA5_A9_D9_MISO)
/FN_NODE: D15.1 (K), SW15.2, SW17.S2
/RGB_DATA: D17.4 (DIN), U1.11 (PA6_A10_D10_MOSI)
/ROW0: D1.2 (A), D2.2 (A), D3.2 (A), D4.2 (A), U1.5 (PA8_A4_D4_SDA)
/ROW1: D5.2 (A), D6.2 (A), D7.2 (A), D8.2 (A), U1.6 (PA9_A5_D5_SCL)
/ROW2: D9.2 (A), D10.2 (A), D11.2 (A), D12.2 (A), U1.7 (PB08_A6_D6_TX)
/ROW3: D13.2 (A), D14.2 (A), D15.2 (A), D16.2 (A), U1.8 (PB09_A7_D7_RX)
GND: D17.3 (VSS), D18.3 (VSS), D19.3 (VSS), D20.3 (VSS), D21.3 (VSS), D22.3 (VSS), D23.3 (VSS), D24.3 (VSS), D25.3 (VSS), D26.3 (VSS), D27.3 (VSS), D28.3 (VSS), D29.3 (VSS), D30.3 (VSS), D31.3 (VSS), D32.3 (VSS), SW17.C, U1.13 (GND)
unnamed: D1.1 (K), SW1.2
unnamed: D2.1 (K), SW2.2
unnamed: D3.1 (K), SW3.2
unnamed: D4.1 (K), SW4.2
unnamed: D5.1 (K), SW5.2
unnamed: D6.1 (K), SW6.2
unnamed: D7.1 (K), SW7.2
unnamed: D8.1 (K), SW8.2
unnamed: D9.1 (K), SW9.2
unnamed: D10.1 (K), SW10.2
unnamed: D11.1 (K), SW11.2
unnamed: D12.1 (K), SW12.2
unnamed: D13.1 (K), SW13.2
unnamed: D14.1 (K), SW14.2
unnamed: D16.1 (K), SW16.2
unnamed: D17.2 (DOUT), D18.4 (DIN)
unnamed: D18.2 (DOUT), D19.4 (DIN)
unnamed: D19.2 (DOUT), D20.4 (DIN)
unnamed: D20.2 (DOUT), D21.4 (DIN)
unnamed: D21.2 (DOUT), D22.4 (DIN)
unnamed: D22.2 (DOUT), D23.4 (DIN)
unnamed: D23.2 (DOUT), D24.4 (DIN)
unnamed: D24.2 (DOUT), D25.4 (DIN)
unnamed: D25.2 (DOUT), D26.4 (DIN)
unnamed: D26.2 (DOUT), D27.4 (DIN)
unnamed: D27.2 (DOUT), D28.4 (DIN)
unnamed: D28.2 (DOUT), D29.4 (DIN)
unnamed: D29.2 (DOUT), D30.4 (DIN)
unnamed: D30.2 (DOUT), D31.4 (DIN)
unnamed: D31.2 (DOUT), D32.4 (DIN)

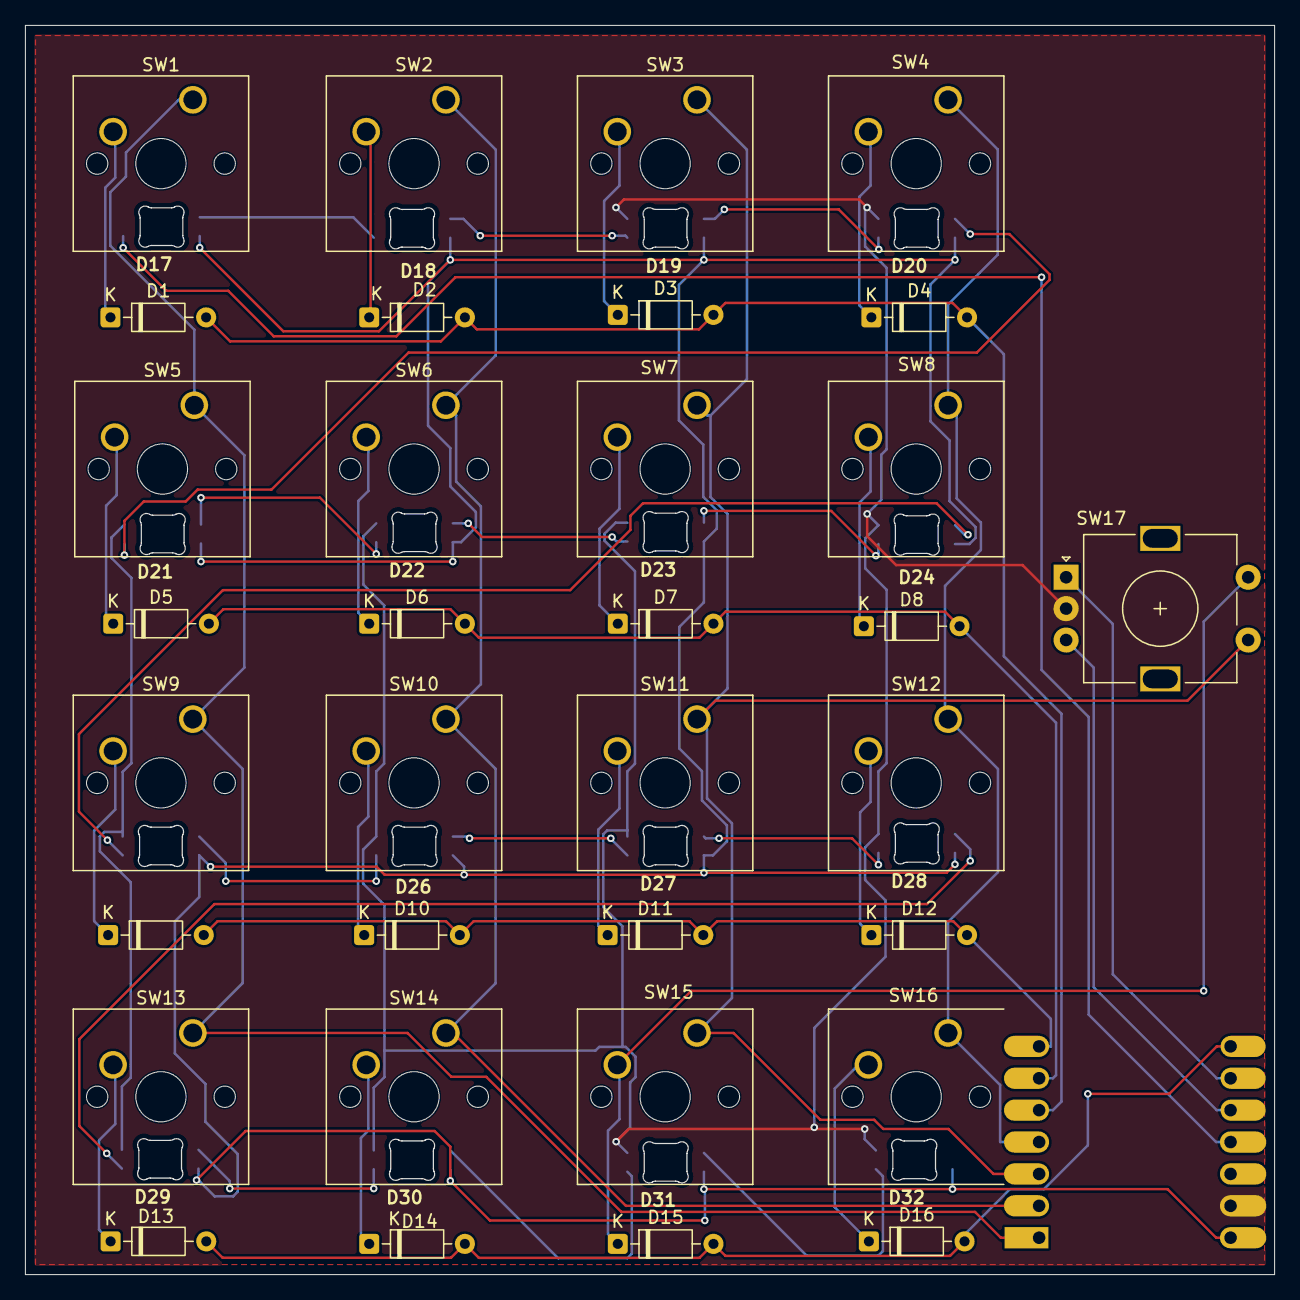
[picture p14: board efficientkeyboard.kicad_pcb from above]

Board: 2 copper layers, 99.5 x 99.5 mm, 50 parts (1 on the bottom side), 44 nets.

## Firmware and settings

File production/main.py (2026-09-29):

# Efficient Keyboard: 4x4 matrix, encoder, LEDs, and 80 character pages.
# Copy main.py and code.py to a XIAO RP2040 running CircuitPython.
# No external library is required. See README.md for Unicode host setup.
# Generated from the repaired KiCad pad/net map; do not change pin order blindly.

import time
import board
import digitalio
import usb_hid

try:
    import neopixel_write
except ImportError:
    neopixel_write = None

COL_PINS = (board.D0, board.D1, board.D2, board.D3)
ROW_PINS = (board.D4, board.D5, board.D6, board.D7)
ENC_A_PIN = board.D8
ENC_B_PIN = board.D9
LED_PIN = board.D10

# Change to -1 if turning clockwise moves backward through the pages.
ENCODER_DIRECTION = 1
DEBOUNCE_SECONDS = 0.025
LONG_PRESS_SECONDS = 0.8
LOOP_SECONDS = 0.002

# Firmware cannot determine the host OS automatically. Windows is the default.
# Windows Unicode needs EnableHexNumpad=1 on the host; see README.md.
HOST_MODES = ("Windows", "Linux", "macOS")
host_mode = 0
page = 0

# The 4x4 board has only 15 output positions per page. SW15 and the encoder
# push switch are wired in parallel at row 3/column 2, so both are CONTROL.
# Tap CONTROL to return to page 0; hold >0.8s to change host OS mode.
# Rotate while holding CONTROL to jump 8 pages at a time.
NORMAL_PAGES = (
    ("QWERTY 1", "qwertyuiopasdfg"),
    ("QWERTY 2", "hjklzxcvbnm \b\n\t"),
    ("Digits", "1234567890-=,./"),
    ("Common symbols", "!@#$%^&*()_+?:;"),
    ("More symbols", "[]{}\\|~<>\"'`A\x1b\x7f"),
)

# Fifteen assigned, noncombining Unicode characters on each page.
# Order and labels are written at build time; no Unicode database is needed
# on the microcontroller.
UNICODE_PAGES = (
    ('Latin 1 1', (0x00A1, 0x00A2, 0x00A3, 0x00A4, 0x00A5, 0x00A6, 0x00A7, 0x00A8, 0x00A9, 0x00AA, 0x00AB, 0x00AC, 0x00AE, 0x00AF, 0x00B0)),
    ('Latin 1 2', (0x00B1, 0x00B2, 0x00B3, 0x00B4, 0x00B5, 0x00B6, 0x00B7, 0x00B8, 0x00B9, 0x00BA, 0x00BB, 0x00BC, 0x00BD, 0x00BE, 0x00BF)),
    ('Latin 1 3', (0x00C0, 0x00C1, 0x00C2, 0x00C3, 0x00C4, 0x00C5, 0x00C6, 0x00C7, 0x00C8, 0x00C9, 0x00CA, 0x00CB, 0x00CC, 0x00CD, 0x00CE)),
    ('Latin Extended A 1', (0x0100, 0x0101, 0x0102, 0x0103, 0x0104, 0x0105, 0x0106, 0x0107, 0x0108, 0x0109, 0x010A, 0x010B, 0x010C, 0x010D, 0x010E)),
    ('Latin Extended A 2', (0x010F, 0x0110, 0x0111, 0x0112, 0x0113, 0x0114, 0x0115, 0x0116, 0x0117, 0x0118, 0x0119, 0x011A, 0x011B, 0x011C, 0x011D)),
    ('Latin Extended A 3', (0x011E, 0x011F, 0x0120, 0x0121, 0x0122, 0x0123, 0x0124, 0x0125, 0x0126, 0x0127, 0x0128, 0x0129, 0x012A, 0x012B, 0x012C)),
    ('Latin Extended A 4', (0x012D, 0x012E, 0x012F, 0x0130, 0x0131, 0x0132, 0x0133, 0x0134, 0x0135, 0x0136, 0x0137, 0x0138, 0x0139, 0x013A, 0x013B)),
    ('Latin Extended A 5', (0x013C, 0x013D, 0x013E, 0x013F, 0x0140, 0x0141, 0x0142, 0x0143, 0x0144, 0x0145, 0x0146, 0x0147, 0x0148, 0x0149, 0x014A)),
    ('Latin Extended B 1', (0x0180, 0x0181, 0x0182, 0x0183, 0x0184, 0x0185, 0x0186, 0x0187, 0x0188, 0x0189, 0x018A, 0x018B, 0x018C, 0x018D, 0x018E)),
    ('Latin Extended B 2', (0x018F, 0x0190, 0x0191, 0x0192, 0x0193, 0x0194, 0x0195, 0x0196, 0x0197, 0x0198, 0x0199, 0x019A, 0x019B, 0x019C, 0x019D)),
    ('Latin Extended B 3', (0x019E, 0x019F, 0x01A0, 0x01A1, 0x01A2, 0x01A3, 0x01A4, 0x01A5, 0x01A6, 0x01A7, 0x01A8, 0x01A9, 0x01AA, 0x01AB, 0x01AC)),
    ('Latin Extended B 4', (0x01AD, 0x01AE, 0x01AF, 0x01B0, 0x01B1, 0x01B2, 0x01B3, 0x01B4, 0x01B5, 0x01B6, 0x01B7, 0x01B8, 0x01B9, 0x01BA, 0x01BB)),
    ('IPA 1', (0x0250, 0x0251, 0x0252, 0x0253, 0x0254, 0x0255, 0x0256, 0x0257, 0x0258, 0x0259, 0x025A, 0x025B, 0x025C, 0x025D, 0x025E)),
    ('IPA 2', (0x025F, 0x0260, 0x0261, 0x0262, 0x0263, 0x0264, 0x0265, 0x0266, 0x0267, 0x0268, 0x0269, 0x026A, 0x026B, 0x026C, 0x026D)),
    ('Greek 1', (0x0370, 0x0371, 0x0372, 0x0373, 0x0374, 0x0375, 0x0376, 0x0377, 0x037A, 0x037B, 0x037C, 0x037D, 0x037E, 0x037F, 0x0384)),
    ('Greek 2', (0x0385, 0x0386, 0x0387, 0x0388, 0x0389, 0x038A, 0x038C, 0x038E, 0x038F, 0x0390, 0x0391, 0x0392, 0x0393, 0x0394, 0x0395)),
    ('Greek 3', (0x0396, 0x0397, 0x0398, 0x0399, 0x039A, 0x039B, 0x039C, 0x039D, 0x039E, 0x039F, 0x03A0, 0x03A1, 0x03A3, 0x03A4, 0x03A5)),
    ('Greek 4', (0x03A6, 0x03A7, 0x03A8, 0x03A9, 0x03AA, 0x03AB, 0x03AC, 0x03AD, 0x03AE, 0x03AF, 0x03B0, 0x03B1, 0x03B2, 0x03B3, 0x03B4)),
    ('Cyrillic 1', (0x0400, 0x0401, 0x0402, 0x0403, 0x0404, 0x0405, 0x0406, 0x0407, 0x0408, 0x0409, 0x040A, 0x040B, 0x040C, 0x040D, 0x040E)),
    ('Cyrillic 2', (0x040F, 0x0410, 0x0411, 0x0412, 0x0413, 0x0414, 0x0415, 0x0416, 0x0417, 0x0418, 0x0419, 0x041A, 0x041B, 0x041C, 0x041D)),
    ('Cyrillic 3', (0x041E, 0x041F, 0x0420, 0x0421, 0x0422, 0x0423, 0x0424, 0x0425, 0x0426, 0x0427, 0x0428, 0x0429, 0x042A, 0x042B, 0x042C)),
    ('Cyrillic 4', (0x042D, 0x042E, 0x042F, 0x0430, 0x0431, 0x0432, 0x0433, 0x0434, 0x0435, 0x0436, 0x0437, 0x0438, 0x0439, 0x043A, 0x043B)),
    ('Cyrillic 5', (0x043C, 0x043D, 0x043E, 0x043F, 0x0440, 0x0441, 0x0442, 0x0443, 0x0444, 0x0445, 0x0446, 0x0447, 0x0448, 0x0449, 0x044A)),
    ('Armenian 1', (0x0531, 0x0532, 0x0533, 0x0534, 0x0535, 0x0536, 0x0537, 0x0538, 0x0539, 0x053A, 0x053B, 0x053C, 0x053D, 0x053E, 0x053F)),
    ('Armenian 2', (0x0540, 0x0541, 0x0542, 0x0543, 0x0544, 0x0545, 0x0546, 0x0547, 0x0548, 0x0549, 0x054A, 0x054B, 0x054C, 0x054D, 0x054E)),
    ('Hebrew 1', (0x05BE, 0x05C0, 0x05C3, 0x05C6, 0x05D0, 0x05D1, 0x05D2, 0x05D3, 0x05D4, 0x05D5, 0x05D6, 0x05D7, 0x05D8, 0x05D9, 0x05DA)),
    ('Hebrew 2', (0x05DB, 0x05DC, 0x05DD, 0x05DE, 0x05DF, 0x05E0, 0x05E1, 0x05E2, 0x05E3, 0x05E4, 0x05E5, 0x05E6, 0x05E7, 0x05E8, 0x05E9)),
    ('Arabic 1', (0x0606, 0x0607, 0x0608, 0x0609, 0x060A, 0x060B, 0x060C, 0x060D, 0x060E, 0x060F, 0x061B, 0x061D, 0x061E, 0x061F, 0x0620)),
    ('Arabic 2', (0x0621, 0x0622, 0x0623, 0x0624, 0x0625, 0x0626, 0x0627, 0x0628, 0x0629, 0x062A, 0x062B, 0x062C, 0x062D, 0x062E, 0x062F)),
    ('Arabic 3', (0x0630, 0x0631, 0x0632, 0x0633, 0x0634, 0x0635, 0x0636, 0x0637, 0x0638, 0x0639, 0x063A, 0x063B, 0x063C, 0x063D, 0x063E)),
    ('Devanagari 1', (0x0904, 0x0905, 0x0906, 0x0907, 0x0908, 0x0909, 0x090A, 0x090B, 0x090C, 0x090D, 0x090E, 0x090F, 0x0910, 0x0911, 0x0912)),
    ('Devanagari 2', (0x0913, 0x0914, 0x0915, 0x0916, 0x0917, 0x0918, 0x0919, 0x091A, 0x091B, 0x091C, 0x091D, 0x091E, 0x091F, 0x0920, 0x0921)),
    ('Bengali 1', (0x0980, 0x0985, 0x0986, 0x0987, 0x0988, 0x0989, 0x098A, 0x098B, 0x098C, 0x098F, 0x0990, 0x0993, 0x0994, 0x0995, 0x0996)),
    ('Tamil 1', (0x0B83, 0x0B85, 0x0B86, 0x0B87, 0x0B88, 0x0B89, 0x0B8A, 0x0B8E, 0x0B8F, 0x0B90, 0x0B92, 0x0B93, 0x0B94, 0x0B95, 0x0B99)),
    ('Thai 1', (0x0E01, 0x0E02, 0x0E03, 0x0E04, 0x0E05, 0x0E06, 0x0E07, 0x0E08, 0x0E09, 0x0E0A, 0x0E0B, 0x0E0C, 0x0E0D, 0x0E0E, 0x0E0F)),
    ('Thai 2', (0x0E10, 0x0E11, 0x0E12, 0x0E13, 0x0E14, 0x0E15, 0x0E16, 0x0E17, 0x0E18, 0x0E19, 0x0E1A, 0x0E1B, 0x0E1C, 0x0E1D, 0x0E1E)),
    ('Georgian 1', (0x10A0, 0x10A1, 0x10A2, 0x10A3, 0x10A4, 0x10A5, 0x10A6, 0x10A7, 0x10A8, 0x10A9, 0x10AA, 0x10AB, 0x10AC, 0x10AD, 0x10AE)),
    ('Georgian 2', (0x10AF, 0x10B0, 0x10B1, 0x10B2, 0x10B3, 0x10B4, 0x10B5, 0x10B6, 0x10B7, 0x10B8, 0x10B9, 0x10BA, 0x10BB, 0x10BC, 0x10BD)),
    ('Ethiopic 1', (0x1200, 0x1201, 0x1202, 0x1203, 0x1204, 0x1205, 0x1206, 0x1207, 0x1208, 0x1209, 0x120A, 0x120B, 0x120C, 0x120D, 0x120E)),
    ('Ethiopic 2', (0x120F, 0x1210, 0x1211, 0x1212, 0x1213, 0x1214, 0x1215, 0x1216, 0x1217, 0x1218, 0x1219, 0x121A, 0x121B, 0x121C, 0x121D)),
    ('Ethiopic 3', (0x121E, 0x121F, 0x1220, 0x1221, 0x1222, 0x1223, 0x1224, 0x1225, 0x1226, 0x1227, 0x1228, 0x1229, 0x122A, 0x122B, 0x122C)),
    ('Ethiopic 4', (0x122D, 0x122E, 0x122F, 0x1230, 0x1231, 0x1232, 0x1233, 0x1234, 0x1235, 0x1236, 0x1237, 0x1238, 0x1239, 0x123A, 0x123B)),
    ('Cherokee 1', (0x13A0, 0x13A1, 0x13A2, 0x13A3, 0x13A4, 0x13A5, 0x13A6, 0x13A7, 0x13A8, 0x13A9, 0x13AA, 0x13AB, 0x13AC, 0x13AD, 0x13AE)),
    ('Cherokee 2', (0x13AF, 0x13B0, 0x13B1, 0x13B2, 0x13B3, 0x13B4, 0x13B5, 0x13B6, 0x13B7, 0x13B8, 0x13B9, 0x13BA, 0x13BB, 0x13BC, 0x13BD)),
    ('Canadian syllabics 1', (0x1400, 0x1401, 0x1402, 0x1403, 0x1404, 0x1405, 0x1406, 0x1407, 0x1408, 0x1409, 0x140A, 0x140B, 0x140C, 0x140D, 0x140E)),
    ('Canadian syllabics 2', (0x140F, 0x1410, 0x1411, 0x1412, 0x1413, 0x1414, 0x1415, 0x1416, 0x1417, 0x1418, 0x1419, 0x141A, 0x141B, 0x141C, 0x141D)),
    ('Canadian syllabics 3', (0x141E, 0x141F, 0x1420, 0x1421, 0x1422, 0x1423, 0x1424, 0x1425, 0x1426, 0x1427, 0x1428, 0x1429, 0x142A, 0x142B, 0x142C)),
    ('Runic 1', (0x16A0, 0x16A1, 0x16A2, 0x16A3, 0x16A4, 0x16A5, 0x16A6, 0x16A7, 0x16A8, 0x16A9, 0x16AA, 0x16AB, 0x16AC, 0x16AD, 0x16AE)),
    ('Runic 2', (0x16AF, 0x16B0, 0x16B1, 0x16B2, 0x16B3, 0x16B4, 0x16B5, 0x16B6, 0x16B7, 0x16B8, 0x16B9, 0x16BA, 0x16BB, 0x16BC, 0x16BD)),
    ('Hiragana 1', (0x3041, 0x3042, 0x3043, 0x3044, 0x3045, 0x3046, 0x3047, 0x3048, 0x3049, 0x304A, 0x304B, 0x304C, 0x304D, 0x304E, 0x304F)),
    ('Hiragana 2', (0x3050, 0x3051, 0x3052, 0x3053, 0x3054, 0x3055, 0x3056, 0x3057, 0x3058, 0x3059, 0x305A, 0x305B, 0x305C, 0x305D, 0x305E)),
    ('Katakana 1', (0x30A0, 0x30A1, 0x30A2, 0x30A3, 0x30A4, 0x30A5, 0x30A6, 0x30A7, 0x30A8, 0x30A9, 0x30AA, 0x30AB, 0x30AC, 0x30AD, 0x30AE)),
    ('Katakana 2', (0x30AF, 0x30B0, 0x30B1, 0x30B2, 0x30B3, 0x30B4, 0x30B5, 0x30B6, 0x30B7, 0x30B8, 0x30B9, 0x30BA, 0x30BB, 0x30BC, 0x30BD)),
    ('CJK 1', (0x4E00, 0x4E01, 0x4E02, 0x4E03, 0x4E04, 0x4E05, 0x4E06, 0x4E07, 0x4E08, 0x4E09, 0x4E0A, 0x4E0B, 0x4E0C, 0x4E0D, 0x4E0E)),
    ('CJK 2', (0x4E0F, 0x4E10, 0x4E11, 0x4E12, 0x4E13, 0x4E14, 0x4E15, 0x4E16, 0x4E17, 0x4E18, 0x4E19, 0x4E1A, 0x4E1B, 0x4E1C, 0x4E1D)),
    ('CJK 3', (0x4E1E, 0x4E1F, 0x4E20, 0x4E21, 0x4E22, 0x4E23, 0x4E24, 0x4E25, 0x4E26, 0x4E27, 0x4E28, 0x4E29, 0x4E2A, 0x4E2B, 0x4E2C)),
    ('Arrows 1', (0x2190, 0x2191, 0x2192, 0x2193, 0x2194, 0x2195, 0x2196, 0x2197, 0x2198, 0x2199, 0x219A, 0x219B, 0x219C, 0x219D, 0x219E)),
    ('Arrows 2', (0x219F, 0x21A0, 0x21A1, 0x21A2, 0x21A3, 0x21A4, 0x21A5, 0x21A6, 0x21A7, 0x21A8, 0x21A9, 0x21AA, 0x21AB, 0x21AC, 0x21AD)),
    ('Math 1', (0x2200, 0x2201, 0x2202, 0x2203, 0x2204, 0x2205, 0x2206, 0x2207, 0x2208, 0x2209, 0x220A, 0x220B, 0x220C, 0x220D, 0x220E)),
    ('Math 2', (0x220F, 0x2210, 0x2211, 0x2212, 0x2213, 0x2214, 0x2215, 0x2216, 0x2217, 0x2218, 0x2219, 0x221A, 0x221B, 0x221C, 0x221D)),
    ('Math 3', (0x221E, 0x221F, 0x2220, 0x2221, 0x2222, 0x2223, 0x2224, 0x2225, 0x2226, 0x2227, 0x2228, 0x2229, 0x222A, 0x222B, 0x222C)),
    ('Technical 1', (0x2300, 0x2301, 0x2302, 0x2303, 0x2304, 0x2305, 0x2306, 0x2307, 0x2308, 0x2309, 0x230A, 0x230B, 0x230C, 0x230D, 0x230E)),
    ('Technical 2', (0x230F, 0x2310, 0x2311, 0x2312, 0x2313, 0x2314, 0x2315, 0x2316, 0x2317, 0x2318, 0x2319, 0x231A, 0x231B, 0x231C, 0x231D)),
    ('Box drawing 1', (0x2500, 0x2501, 0x2502, 0x2503, 0x2504, 0x2505, 0x2506, 0x2507, 0x2508, 0x2509, 0x250A, 0x250B, 0x250C, 0x250D, 0x250E)),
    ('Box drawing 2', (0x250F, 0x2510, 0x2511, 0x2512, 0x2513, 0x2514, 0x2515, 0x2516, 0x2517, 0x2518, 0x2519, 0x251A, 0x251B, 0x251C, 0x251D)),
    ('Geometric 1', (0x25A0, 0x25A1, 0x25A2, 0x25A3, 0x25A4, 0x25A5, 0x25A6, 0x25A7, 0x25A8, 0x25A9, 0x25AA, 0x25AB, 0x25AC, 0x25AD, 0x25AE)),
    ('Geometric 2', (0x25AF, 0x25B0, 0x25B1, 0x25B2, 0x25B3, 0x25B4, 0x25B5, 0x25B6, 0x25B7, 0x25B8, 0x25B9, 0x25BA, 0x25BB, 0x25BC, 0x25BD)),
    ('Misc signs 1', (0x2600, 0x2601, 0x2602, 0x2603, 0x2604, 0x2605, 0x2606, 0x2607, 0x2608, 0x2609, 0x260A, 0x260B, 0x260C, 0x260D, 0x260E)),
    ('Misc signs 2', (0x260F, 0x2610, 0x2611, 0x2612, 0x2613, 0x2614, 0x2615, 0x2616, 0x2617, 0x2618, 0x2619, 0x261A, 0x261B, 0x261C, 0x261D)),
    ('Misc signs 3', (0x261E, 0x261F, 0x2620, 0x2621, 0x2622, 0x2623, 0x2624, 0x2625, 0x2626, 0x2627, 0x2628, 0x2629, 0x262A, 0x262B, 0x262C)),
    ('Dingbats 1', (0x2700, 0x2701, 0x2702, 0x2703, 0x2704, 0x2705, 0x2706, 0x2707, 0x2708, 0x2709, 0x270A, 0x270B, 0x270C, 0x270D, 0x270E)),
    ('Dingbats 2', (0x270F, 0x2710, 0x2711, 0x2712, 0x2713, 0x2714, 0x2715, 0x2716, 0x2717, 0x2718, 0x2719, 0x271A, 0x271B, 0x271C, 0x271D)),
    ('Braille 1', (0x2800, 0x2801, 0x2802, 0x2803, 0x2804, 0x2805, 0x2806, 0x2807, 0x2808, 0x2809, 0x280A, 0x280B, 0x280C, 0x280D, 0x280E)),
    ('Braille 2', (0x280F, 0x2810, 0x2811, 0x2812, 0x2813, 0x2814, 0x2815, 0x2816, 0x2817, 0x2818, 0x2819, 0x281A, 0x281B, 0x281C, 0x281D)),
    ('Braille 3', (0x281E, 0x281F, 0x2820, 0x2821, 0x2822, 0x2823, 0x2824, 0x2825, 0x2826, 0x2827, 0x2828, 0x2829, 0x282A, 0x282B, 0x282C)),
)

PAGE_COUNT = len(NORMAL_PAGES) + len(UNICODE_PAGES)

def keyboard_device():
    for device in usb_hid.devices:
        if device.usage_page == 0x01 and device.usage == 0x06:
            return device
    raise RuntimeError("USB keyboard HID device is not enabled")

keyboard = keyboard_device()
report = bytearray(8)

def report_key(modifier=0, usage=0):
    report[0] = modifier
    report[1] = 0
    report[2] = usage
    for i in range(3, 8):
        report[i] = 0
    keyboard.send_report(report)

def tap(usage, modifier=0):
    report_key(modifier, usage)
    time.sleep(0.004)
    report_key(0, 0)
    time.sleep(0.004)

def tap_held(usage, modifier):
    report_key(modifier, usage)
    time.sleep(0.004)
    report_key(modifier, 0)
    time.sleep(0.004)

SHIFT = 0x02
CTRL = 0x01
ALT = 0x04

SPECIAL = {
    "\b": 0x2A, "\t": 0x2B, "\n": 0x28, " ": 0x2C,
    "\x1b": 0x29, "\x7f": 0x4C,
}
PLAIN = {
    "-": 0x2D, "=": 0x2E, "[": 0x2F, "]": 0x30,
    "\\": 0x31, ";": 0x33, "'": 0x34, "`": 0x35,
    ",": 0x36, ".": 0x37, "/": 0x38,
}
SHIFTED = {
    "!": "1", "@": "2", "#": "3", "$": "4", "%": "5",
    "^": "6", "&": "7", "*": "8", "(": "9", ")": "0",
    "_": "-", "+": "=", "{": "[", "}": "]", "|": "\\",
    ":": ";", "\"": "'", "~": "`", "<": ",", ">": ".", "?": "/",
}

def ascii_usage(ch):
    modifier = 0
    if ch in SHIFTED:
        ch = SHIFTED[ch]
        modifier = SHIFT
    if "A" <= ch <= "Z":
        modifier = SHIFT
        ch = ch.lower()
    if "a" <= ch <= "z":
        return 0x04 + ord(ch) - ord("a"), modifier
    if "1" <= ch <= "9":
        return 0x1E + ord(ch) - ord("1"), modifier
    if ch == "0":
        return 0x27, modifier
    if ch in PLAIN:
        return PLAIN[ch], modifier
    return SPECIAL[ch], modifier

def send_ascii(ch):
    usage, modifier = ascii_usage(ch)
    tap(usage, modifier)

def hex_usage(ch, numpad=False):
    if numpad and "1" <= ch <= "9":
        return 0x59 + ord(ch) - ord("1")
    if numpad and ch == "0":
        return 0x62
    return ascii_usage(ch.lower())[0]

def send_unicode(codepoint):
    digits = "%04X" % codepoint
    if host_mode == 0:  # Windows HexNumpad: Alt, keypad +, hex, release.
        report_key(ALT, 0)
        time.sleep(0.006)
        tap_held(0x57, ALT)  # Keypad +
        for digit in digits:
            tap_held(hex_usage(digit, True), ALT)
        report_key(0, 0)
    elif host_mode == 1:  # Linux GTK/Qt: Ctrl+Shift+U, hex, Space.
        tap(0x18, CTRL | SHIFT)  # U
        for digit in digits:
            tap(hex_usage(digit))
        tap(0x2C)
    else:  # macOS Unicode Hex Input source: hold Option, type hex.
        report_key(ALT, 0)
        time.sleep(0.006)
        for digit in digits:
            tap_held(hex_usage(digit), ALT)
        report_key(0, 0)

def emit_key(index):
    if page < len(NORMAL_PAGES):
        send_ascii(NORMAL_PAGES[page][1][index])
    else:
        send_unicode(UNICODE_PAGES[page - len(NORMAL_PAGES)][1][index])

# Diode anodes are on ROW nets and cathodes face the switch/COL side.
# Drive one row high at a time; read columns with pulldowns.
rows = []
for pin in ROW_PINS:
    io = digitalio.DigitalInOut(pin)
    io.direction = digitalio.Direction.OUTPUT
    io.value = False
    rows.append(io)
cols = []
for pin in COL_PINS:
    io = digitalio.DigitalInOut(pin)
    io.direction = digitalio.Direction.INPUT
    io.pull = digitalio.Pull.DOWN
    cols.append(io)

encoder_a = digitalio.DigitalInOut(ENC_A_PIN)
encoder_a.direction = digitalio.Direction.INPUT
encoder_a.pull = digitalio.Pull.UP
encoder_b = digitalio.DigitalInOut(ENC_B_PIN)
encoder_b.direction = digitalio.Direction.INPUT
encoder_b.pull = digitalio.Pull.UP
encoder_previous = (int(encoder_a.value) << 1) | int(encoder_b.value)
encoder_accum = 0
ENCODER_TRANSITIONS = (0, -1, 1, 0, 1, 0, 0, -1,
                       -1, 0, 0, 1, 0, 1, -1, 0)

led = None
if neopixel_write is not None:
    try:
        led = digitalio.DigitalInOut(LED_PIN)
        led.direction = digitalio.Direction.OUTPUT
    except Exception:
        led = None

def show_page():
    if led is None:
        return
    try:
        # One through sixteen lit LEDs show position within a 16-page group.
        # Color changes every group; status brightness stays low.
        colors = ((8, 1, 0), (8, 5, 0), (1, 8, 0),
                  (0, 8, 4), (0, 3, 8), (4, 0, 8))
        red, green, blue = colors[(page // 16) % len(colors)]
        lit = (page % 16) + 1
        pixels = bytearray(16 * 3)
        for n in range(lit):
            pixels[3*n] = green   # SK6812MINI-E uses GRB wire order.
            pixels[3*n+1] = red
            pixels[3*n+2] = blue
        neopixel_write.neopixel_write(led, pixels)
    except Exception:
        pass  # The keyboard continues to type if the LED chain is absent.

def show_mode():
    if led is None:
        return
    try:
        pixels = bytearray(16 * 3)
        for n in range(host_mode + 1):
            pixels[3*n] = 0
            pixels[3*n+1] = 8
            pixels[3*n+2] = 8
        neopixel_write.neopixel_write(led, pixels)
        time.sleep(0.35)
    except Exception:
        pass
    show_page()

raw = [False] * 16
stable = [False] * 16
changed = [time.monotonic()] * 16
control_started = None
control_rotated = False

def scan_matrix(now):
    global page, host_mode, control_started, control_rotated
    for row_number, row_io in enumerate(rows):
        row_io.value = True
        time.sleep(0.0001)
        for col_number, col_io in enumerate(cols):
            index = row_number * 4 + col_number
            observed = bool(col_io.value)
            if observed != raw[index]:
                raw[index] = observed
                changed[index] = now
            elif observed != stable[index] and now - changed[index] >= DEBOUNCE_SECONDS:
                stable[index] = observed
                if index == 14:  # SW15 and encoder push: shared net.
                    if observed:
                        control_started = now
                        control_rotated = False
                    elif control_started is not None:
                        if not control_rotated:
                            if now - control_started >= LONG_PRESS_SECONDS:
                                host_mode = (host_mode + 1) % len(HOST_MODES)
                                show_mode()
                            else:
                                page = 0
                                show_page()
                        control_started = None
                elif observed:
                    emit_key(index if index < 14 else 14)
        row_io.value = False

def scan_encoder():
    global encoder_previous, encoder_accum, page, control_rotated
    current = (int(encoder_a.value) << 1) | int(encoder_b.value)
    if current != encoder_previous:
        transition = (encoder_previous << 2) | current
        encoder_accum += ENCODER_TRANSITIONS[transition]
        encoder_previous = current
        if encoder_accum >= 4 or encoder_accum <= -4:
            step = 1 if encoder_accum > 0 else -1
            encoder_accum = 0
            if ENCODER_DIRECTION < 0:
                step = -step
            if stable[14]:
                step *= 8
                control_rotated = True
            page = (page + step) % PAGE_COUNT
            show_page()

show_page()
while True:
    current_time = time.monotonic()
    scan_matrix(current_time)
    scan_encoder()
    time.sleep(LOOP_SECONDS)

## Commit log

2026-09-29 Enhance README with project details and specifications
    Expanded README to include detailed features, CAD, PCB, firmware, and BOM sections.
2026-09-29 Enhance README with additional images and details
    Updated images and descriptions for CAD, PCB, and firmware sections.
2026-09-29 Add BOM image to README
